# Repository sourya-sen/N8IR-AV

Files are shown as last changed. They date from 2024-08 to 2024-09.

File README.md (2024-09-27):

The N8IR is a standalone experimental audiovisual synthesizer and phrase generator. Designed with a simple set of interconnected audio and visual controls and a modular patchbay, the N8IR creates tightly synced audiovisual patterns, powered by a Teensy microcontroller and CMOS logic chips.

Detailed manual and documentation to follow.

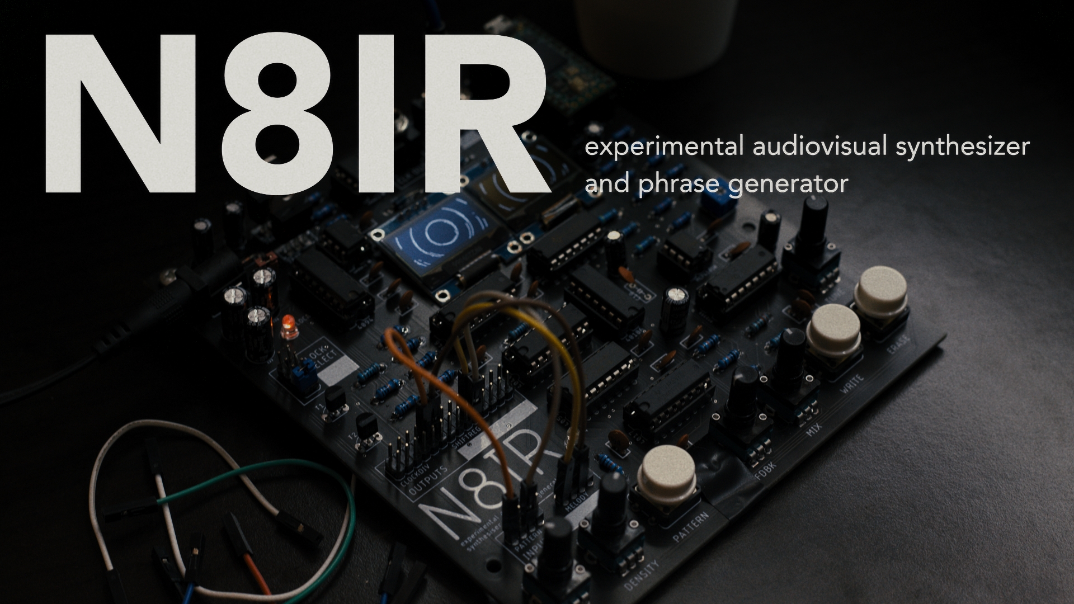
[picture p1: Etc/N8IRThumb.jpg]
N8IR


This project would not be possible without the knowledge shared on the electro-music forums and previous work by Andy Murkin.

More on Lunetta Synthesis: https://hackaday.com/series_of_posts/logic-noise/ <br>
The Melody Generator Circuit on the electro-music forums: https://electro-music.com/forum/topic-42552.html<br>
Andy Murkin’s delay circuit: https://andymurkin.wordpress.com/2018/03/19/piezos-electrets-pt-4-electronics-and-a-very-very-simple-pt2399-echo-delay/<br>

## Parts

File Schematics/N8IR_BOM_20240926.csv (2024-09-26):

Part | Value | Device | Package | Description | CIIVA_IDS | CODE__JEDEC | COMPONENT_LINK_1_DESCRIPTION | COMPONENT_LINK_1_URL | COMPONENT_LINK_3_DESCRIPTION | COMPONENT_LINK_3_URL | DATASHEET | DATASHEET_VERSION | FOOTPRINT_VARIANT_NAME_0 | IMPORTED | IMPORTED_FROM | IMPORT_TS | MF | MPN | PACKAGE | PACKAGE_DESCRIPTION | PACKAGE_VERSION | PIN_0_0_3_INSIDE_EDGE | POPULARITY | PREFIX | PROD_ID | RELEASE_DATE | SF_ID | SF_SKU | SPICEPREFIX | VALUE | VAULT_GUID | VAULT_REVISION
339 | TLC339P | TLC339P | DIL14 | COMPARATOR |  |  |  |  |  |  |  |  |  |  |  |  |  |  |  |  |  |  | 3
4017 | 4017N | 4017N | DIL16 | COUNTER/DIVIDER |  |  |  |  |  |  |  |  |  |  |  |  |  |  |  |  |  |  | 2
4040 | 4040N | 4040N | DIL16 | 12-stage binary/ripple COUNTER |  |  |  |  |  |  |  |  |  |  |  |  |  |  |  |  |  |  | 2
4046 | 4046N | 4046N | DIL16 | Micropower PLL |  |  |  |  |  |  |  |  |  |  |  |  |  |  |  |  |  |  | 1
4051 | 4051N | 4051N | DIL16 | 8-channel ANALOG MULTIPLEXER |  |  |  |  |  |  |  |  |  |  |  |  |  |  |  |  |  |  | 15
4094 | 4094N | 4094N | DIL16 | 8-stage SHIFT/STORE REGISTER, tri-state |  |  |  |  |  |  |  |  |  |  |  |  |  |  |  |  |  |  | 1
7805 | 7805 | 78XXS | 78XXS | VOLTAGE REGULATOR |  |  |  |  |  |  |  |  |  |  |  |  |  |  |  |  |  |  | 18
7809 | 7809 | 78XXS | 78XXS | VOLTAGE REGULATOR |  |  |  |  |  |  |  |  |  |  |  |  |  |  |  |  |  |  | 18
40106 | 40106N | 40106N | DIL14 | Hex SCHMITT TRIGGER |  |  |  |  |  |  |  |  |  |  |  |  |  |  |  |  |  |  | 4
B1 | TEENSYNOSILK | TEENSYNOSILK | TEENSY_NOSILK | Teensy Footprint |  |  |  |  |  |  |  |  |  |  |  |  |  |  |  |  |  |  |  |  |  |  | DEV-12646
C1 | 0.1uF | 0.1UF-KIT-EZ-50V-20% | CAP-PTH-SMALL-KIT | 0.1µF ceramic capacitors |  |  |  |  |  |  |  |  |  |  |  |  |  |  |  |  |  |  |  |  | CAP-08370 |  |  |  |  | 0.1uF
C2 | 0.1uF | 0.1UF-KIT-EZ-50V-20% | CAP-PTH-SMALL-KIT | 0.1µF ceramic capacitors |  |  |  |  |  |  |  |  |  |  |  |  |  |  |  |  |  |  |  |  | CAP-08370 |  |  |  |  | 0.1uF
C3 | 0.1uF | 0.1UF-KIT-EZ-50V-20% | CAP-PTH-SMALL-KIT | 0.1µF ceramic capacitors |  |  |  |  |  |  |  |  |  |  |  |  |  |  |  |  |  |  |  |  | CAP-08370 |  |  |  |  | 0.1uF
C4 | 0.1uF | 0.1UF-KIT-EZ-50V-20% | CAP-PTH-SMALL-KIT | 0.1µF ceramic capacitors |  |  |  |  |  |  |  |  |  |  |  |  |  |  |  |  |  |  |  |  | CAP-08370 |  |  |  |  | 0.1uF
C5 | 0.1uF | 0.1UF-KIT-EZ-50V-20% | CAP-PTH-SMALL-KIT | 0.1µF ceramic capacitors |  |  |  |  |  |  |  |  |  |  |  |  |  |  |  |  |  |  |  |  | CAP-08370 |  |  |  |  | 0.1uF
C6 | 0.1uF | 0.1UF-KIT-EZ-50V-20% | CAP-PTH-SMALL-KIT | 0.1µF ceramic capacitors |  |  |  |  |  |  |  |  |  |  |  |  |  |  |  |  |  |  |  |  | CAP-08370 |  |  |  |  | 0.1uF
C7 | 100uF | 100UF-POLAR-RADIAL-2.5MM-25V-20% | CPOL-RADIAL-2.5MM-6.5MM | 100µF polarized capacitors |  |  |  |  |  |  |  |  |  |  |  |  |  |  |  |  |  |  |  |  | CAP-08439 |  |  |  |  | 100uF
C8 | 0.1uF | 0.1UF-KIT-EZ-50V-20% | CAP-PTH-SMALL-KIT | 0.1µF ceramic capacitors |  |  |  |  |  |  |  |  |  |  |  |  |  |  |  |  |  |  |  |  | CAP-08370 |  |  |  |  | 0.1uF
C9 | 10uF | 10UF-POLAR-RADIAL-2.5MM-25V-20% | CPOL-RADIAL-2.5MM-5MM | 10.0µF polarized capacitors |  |  |  |  |  |  |  |  |  |  |  |  |  |  |  |  |  |  |  |  | CAP-08440 |  |  |  |  | 10uF
C10 | 10uF | 10UF-POLAR-RADIAL-2.5MM-25V-20% | CPOL-RADIAL-2.5MM-5MM | 10.0µF polarized capacitors |  |  |  |  |  |  |  |  |  |  |  |  |  |  |  |  |  |  |  |  | CAP-08440 |  |  |  |  | 10uF
C11 | 0.1uF | 0.1UF-KIT-EZ-50V-20% | CAP-PTH-SMALL-KIT | 0.1µF ceramic capacitors |  |  |  |  |  |  |  |  |  |  |  |  |  |  |  |  |  |  |  |  | CAP-08370 |  |  |  |  | 0.1uF
C12 | 0.1uF | 0.1UF-KIT-EZ-50V-20% | CAP-PTH-SMALL-KIT | 0.1µF ceramic capacitors |  |  |  |  |  |  |  |  |  |  |  |  |  |  |  |  |  |  |  |  | CAP-08370 |  |  |  |  | 0.1uF
C13 | 0.1uF | 0.1UF-KIT-EZ-50V-20% | CAP-PTH-SMALL-KIT | 0.1µF ceramic capacitors |  |  |  |  |  |  |  |  |  |  |  |  |  |  |  |  |  |  |  |  | CAP-08370 |  |  |  |  | 0.1uF
C14 | 10uF | 10UF-POLAR-RADIAL-2.5MM-25V-20% | CPOL-RADIAL-2.5MM-5MM | 10.0µF polarized capacitors |  |  |  |  |  |  |  |  |  |  |  |  |  |  |  |  |  |  |  |  | CAP-08440 |  |  |  |  | 10uF
C15 | 10uF | 10UF-POLAR-RADIAL-2.5MM-25V-20% | CPOL-RADIAL-2.5MM-5MM | 10.0µF polarized capacitors |  |  |  |  |  |  |  |  |  |  |  |  |  |  |  |  |  |  |  |  | CAP-08440 |  |  |  |  | 10uF
C16 | 0.1uF | 0.1UF-KIT-EZ-50V-20% | CAP-PTH-SMALL-KIT | 0.1µF ceramic capacitors |  |  |  |  |  |  |  |  |  |  |  |  |  |  |  |  |  |  |  |  | CAP-08370 |  |  |  |  | 0.1uF
C17 | 0.1uF | 0.1UF-KIT-EZ-50V-20% | CAP-PTH-SMALL-KIT | 0.1µF ceramic capacitors |  |  |  |  |  |  |  |  |  |  |  |  |  |  |  |  |  |  |  |  | CAP-08370 |  |  |  |  | 0.1uF
C18 | 0.1uF | 0.1UF-KIT-EZ-50V-20% | CAP-PTH-SMALL-KIT | 0.1µF ceramic capacitors |  |  |  |  |  |  |  |  |  |  |  |  |  |  |  |  |  |  |  |  | CAP-08370 |  |  |  |  | 0.1uF
C19 | .1uF | C5/3.5 | C5B3.5 | CAPACITOR |  |  |  |  |  |  |  |  |  |  |  |  |  |  |  |  |  |  | 3
C20 | 47uF | 10UF-POLAR-RADIAL-2.5MM-25V-20% | CPOL-RADIAL-2.5MM-5MM | 10.0µF polarized capacitors |  |  |  |  |  |  |  |  |  |  |  |  |  |  |  |  |  |  |  |  | CAP-08440 |  |  |  |  | 10uF
C21 | 0.1uF | 0.1UF-KIT-EZ-50V-20% | CAP-PTH-SMALL-KIT | 0.1µF ceramic capacitors |  |  |  |  |  |  |  |  |  |  |  |  |  |  |  |  |  |  |  |  | CAP-08370 |  |  |  |  | 0.1uF
C22 | 0.1uF | 0.1UF-KIT-EZ-50V-20% | CAP-PTH-SMALL-KIT | 0.1µF ceramic capacitors |  |  |  |  |  |  |  |  |  |  |  |  |  |  |  |  |  |  |  |  | CAP-08370 |  |  |  |  | 0.1uF
C23 | 100uF | 100UF-POLAR-RADIAL-2.5MM-25V-20% | CPOL-RADIAL-2.5MM-6.5MM | 100µF polarized capacitors |  |  |  |  |  |  |  |  |  |  |  |  |  |  |  |  |  |  |  |  | CAP-08439 |  |  |  |  | 100uF
C24 | 0.1uF | 0.1UF-KIT-EZ-50V-20% | CAP-PTH-SMALL-KIT | 0.1µF ceramic capacitors |  |  |  |  |  |  |  |  |  |  |  |  |  |  |  |  |  |  |  |  | CAP-08370 |  |  |  |  | 0.1uF
C25 | 0.1uF | 0.1UF-KIT-EZ-50V-20% | CAP-PTH-SMALL-KIT | 0.1µF ceramic capacitors |  |  |  |  |  |  |  |  |  |  |  |  |  |  |  |  |  |  |  |  | CAP-08370 |  |  |  |  | 0.1uF
C26 | 10uF | 10UF-POLAR-RADIAL-2.5MM-25V-20% | CPOL-RADIAL-2.5MM-5MM | 10.0µF polarized capacitors |  |  |  |  |  |  |  |  |  |  |  |  |  |  |  |  |  |  |  |  | CAP-08440 |  |  |  |  | 10uF
C27 | 100uF | 100UF-POLAR-RADIAL-2.5MM-25V-20% | CPOL-RADIAL-2.5MM-6.5MM | 100µF polarized capacitors |  |  |  |  |  |  |  |  |  |  |  |  |  |  |  |  |  |  |  |  | CAP-08439 |  |  |  |  | 100uF
CLOCK |  | LED3MM | LED_3MM | LED (Generic) |  |  |  |  |  |  |  |  |  |  |  |  |  |  |  |  |  |  |  |  | DIO-08794
CLOCKDIV |  | PINHD-2X6 | 2X06 | PIN HEADER |  |  |  |  |  |  |  |  |  |  |  |  |  |  |  |  |  |  | 8
CLOCKOUT | WQP-PJ301M-12_JACK | WQP-PJ301M-12_JACK | WQP-PJ301M-12_JACK
D1 | BAT42 | BAT42 | DO35-10 | DIODE |  |  |  |  |  |  |  |  |  |  |  |  |  |  |  |  |  |  | 0
D2 | BAT42 | BAT42 | DO35-10 | DIODE |  |  |  |  |  |  |  |  |  |  |  |  |  |  |  |  |  |  | 0
D3 | 1N4148 | SMALL_DIODEDO35-7 | DO35-7 | Small Signal Diode
DENSITY | 100k | 9MM_SNAP-IN_POT_ | 9MM_SNAP-IN_POT | 9mm vertical snap-in pot, Alpha / Panasonic style
ERASE |  | MOMENTARY-SWITCH-SPST-PTH-12MM | TACTILE_SWITCH_PTH_12MM | Momentary Switch (Pushbutton) - SPST |  |  |  |  |  |  |  |  |  |  |  |  |  |  |  |  |  |  |  |  | SWCH-09185 |  |  | COM-09190
FDBK | 100k | 9MM_SNAP-IN_POT_ | 9MM_SNAP-IN_POT | 9mm vertical snap-in pot, Alpha / Panasonic style
FREQ | 100k | 9MM_SNAP-IN_POT_ | 9MM_SNAP-IN_POT | 9mm vertical snap-in pot, Alpha / Panasonic style
J1 |  | POWER_JACKPOWER_JACK_SLOT | POWER_JACK_PTH_SLOT | Power Jack Connector |  |  |  |  |  |  |  |  |  |  |  |  |  |  |  |  |  |  |  |  | CONN-08197
JP4 |  | PINHD-2X4 | 2X04 | PIN HEADER
LM358-1 | LM358 | LM358 | DIP08 | LM358 |  |  |  |  |  |  |  |  |  |  |  |  |  |  |  |  |  |  |  |  | IC-09172 |  |  |  |  | LM358
LM358-2 | LM358 | LM358 | DIP08 | LM358 |  |  |  |  |  |  |  |  |  |  |  |  |  |  |  |  |  |  |  |  | IC-09172 |  |  |  |  | LM358
MCP41050 | MCP41050 | MICROCHIP_MCP41050-I-PMICROCHIP_MCP41050-I-P_0_0 | MICROCHIP_MCP41050-I-P_0 | IN-DPOT-MCP41XXX-8 | 965827 | MS-001 | Manufacturer URL | http://www.microchip.com/ | Package Specification | http://www.microchip.com/stellent/groups/techpub_sg/documents/packagingspec/en012702.pdf | http://ww1.microchip.com/downloads/en/DeviceDoc/11195c.pdf | Jul-2003 | Manufacturer Recommended | yes | vault | 1521866433 | Microchip | MCP41050-I/P | PDIP300-P8 | 8-Lead Plastic Dual In-Line (P) - 300 mil Body [PDIP] | revBB, Aug-2009 | clock |  | U |  | 1331947897 |  |  |  |  | 8499BC26-C1FC-4B90-9420-E4A686EE06B6 | 41824CE8-0B62-48CA-9CA7-4E0BC05643CA
MELODY |  | PINHD-1X4 | 1X04 | PIN HEADER |  |  |  |  |  |  |  |  |  |  |  |  |  |  |  |  |  |  | 91
MIX | 100k | 9MM_SNAP-IN_POT_ | 9MM_SNAP-IN_POT | 9mm vertical snap-in pot, Alpha / Panasonic style
MS4 |  | LED3MM | LED_3MM | LED (Generic) |  |  |  |  |  |  |  |  |  |  |  |  |  |  |  |  |  |  |  |  | DIO-08794
OL96$1 | OLED_0.96_I2C | OLED_0.96_I2C | OLED_0.96_I2C
OL96$2 | OLED_0.96_I2C | OLED_0.96_I2C | OLED_0.96_I2C
OUTPUT | WQP-PJ301M-12_JACK | WQP-PJ301M-12_JACK | WQP-PJ301M-12_JACK
PATTERN |  | PINHD-1X4 | 1X04 | PIN HEADER |  |  |  |  |  |  |  |  |  |  |  |  |  |  |  |  |  |  | 91
PATTERNOFFSET |  | MOMENTARY-SWITCH-SPST-PTH-12MM | TACTILE_SWITCH_PTH_12MM | Momentary Switch (Pushbutton) - SPST |  |  |  |  |  |  |  |  |  |  |  |  |  |  |  |  |  |  |  |  | SWCH-09185 |  |  | COM-09190
PT2399 | PT2399 | PT2399 | DIP-16
R1 | 10k | RESISTOR7MM | 7MM_RESISTOR | Standard resistor, various versions
R2 | 10k | RESISTOR7MM | 7MM_RESISTOR | Standard resistor, various versions
R3 | 10k | RESISTOR7MM | 7MM_RESISTOR | Standard resistor, various versions
R4 | 10k | RESISTOR7MM | 7MM_RESISTOR | Standard resistor, various versions
R5 | 4.7k | RESISTOR7MM | 7MM_RESISTOR | Standard resistor, various versions
R6 | 1k | RESISTOR7MM | 7MM_RESISTOR | Standard resistor, various versions
R7 | 10k | RESISTOR7MM | 7MM_RESISTOR | Standard resistor, various versions
R8 | 10k | RESISTOR7MM | 7MM_RESISTOR | Standard resistor, various versions
R9 | 4.7k | RESISTOR7MM | 7MM_RESISTOR | Standard resistor, various versions
R10 | 4.7k | RESISTOR7MM | 7MM_RESISTOR | Standard resistor, various versions
R11 | 10k | RESISTOR7MM | 7MM_RESISTOR | Standard resistor, various versions
R12 | 4.7k | RESISTOR7MM | 7MM_RESISTOR | Standard resistor, various versions
R13 | 10k | RESISTOR7MM | 7MM_RESISTOR | Standard resistor, various versions
R14 | 4.7k | RESISTOR7MM | 7MM_RESISTOR | Standard resistor, various versions
R15 | 100k | RESISTOR7MM | 7MM_RESISTOR | Standard resistor, various versions
R16 | 100k | RESISTOR7MM | 7MM_RESISTOR | Standard resistor, various versions
R17 | 100k | RESISTOR7MM | 7MM_RESISTOR | Standard resistor, various versions
R18 | 10k | RESISTOR7MM | 7MM_RESISTOR | Standard resistor, various versions
R19 | 100k | RESISTOR7MM | 7MM_RESISTOR | Standard resistor, various versions
R20 | 100k | RESISTOR7MM | 7MM_RESISTOR | Standard resistor, various versions
R21 | 10k | RESISTOR7MM | 7MM_RESISTOR | Standard resistor, various versions
R22 | 1k | RESISTOR7MM | 7MM_RESISTOR | Standard resistor, various versions
R23 | 10k | RESISTOR7MM | 7MM_RESISTOR | Standard resistor, various versions
R24 | 10k | RESISTOR7MM | 7MM_RESISTOR | Standard resistor, various versions
R25 | 10k | RESISTOR7MM | 7MM_RESISTOR | Standard resistor, various versions
R26 | 1k | RESISTOR7MM | 7MM_RESISTOR | Standard resistor, various versions
R27 | 100k | RESISTOR7MM | 7MM_RESISTOR | Standard resistor, various versions
R28 | LDR | R-EU_0204/2V | 0204V | RESISTOR, European symbol |  |  |  |  |  |  |  |  |  |  |  |  |  |  |  |  |  |  | 11 |  |  |  |  |  | R
R29 | 100k | RESISTOR7MM | 7MM_RESISTOR | Standard resistor, various versions
R30 | 2.2k | RESISTOR7MM | 7MM_RESISTOR | Standard resistor, various versions
R31 | 100k | RESISTOR7MM | 7MM_RESISTOR | Standard resistor, various versions
R32 | 10k | RESISTOR7MM | 7MM_RESISTOR | Standard resistor, various versions
R33 | 100k | RESISTOR7MM | 7MM_RESISTOR | Standard resistor, various versions
SHIFTREG |  | PINHD-2X8 | 2X08 | PIN HEADER |  |  |  |  |  |  |  |  |  |  |  |  |  |  |  |  |  |  | 6
SPEED | 100k | 9MM_SNAP-IN_POT_ | 9MM_SNAP-IN_POT | 9mm vertical snap-in pot, Alpha / Panasonic style
T1 |  | 2N4401-NPN-TO92-EBC | TO92-EBC | NPN Transistror |  |  |  |  |  |  |  |  |  |  |  |  |  |  |  |  |  |  | 0
T2 |  | 2N4401-NPN-TO92-EBC | TO92-EBC | NPN Transistror |  |  |  |  |  |  |  |  |  |  |  |  |  |  |  |  |  |  | 0
TNSYPWR |  | PINHD-1X2 | 1X02 | PIN HEADER |  |  |  |  |  |  |  |  |  |  |  |  |  |  |  |  |  |  | 98
VR4 |  | BOURNS_3362P_TRIMMERP | BOURNS_3362P_TRIMMER | 3362 Series
WRITE |  | MOMENTARY-SWITCH-SPST-PTH-12MM | TACTILE_SWITCH_PTH_12MM | Momentary Switch (Pushbutton) - SPST |  |  |  |  |  |  |  |  |  |  |  |  |  |  |  |  |  |  |  |  | SWCH-09185 |  |  | COM-09190

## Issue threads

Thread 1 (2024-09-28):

BOM questions

extremenerble, 2024-09-28:
Hello!

Saw your post on r/synthdiy and am very interested in this project! Two BOM parts questions:

1. What is the value of VR4 trimmer? The BOM I exported from Eagle doesn't have a value
2. Is the C19 capacitor a film type? It's the same value as the passive ceramics but has a different footprint

Thank you for your time and making this available publicly!

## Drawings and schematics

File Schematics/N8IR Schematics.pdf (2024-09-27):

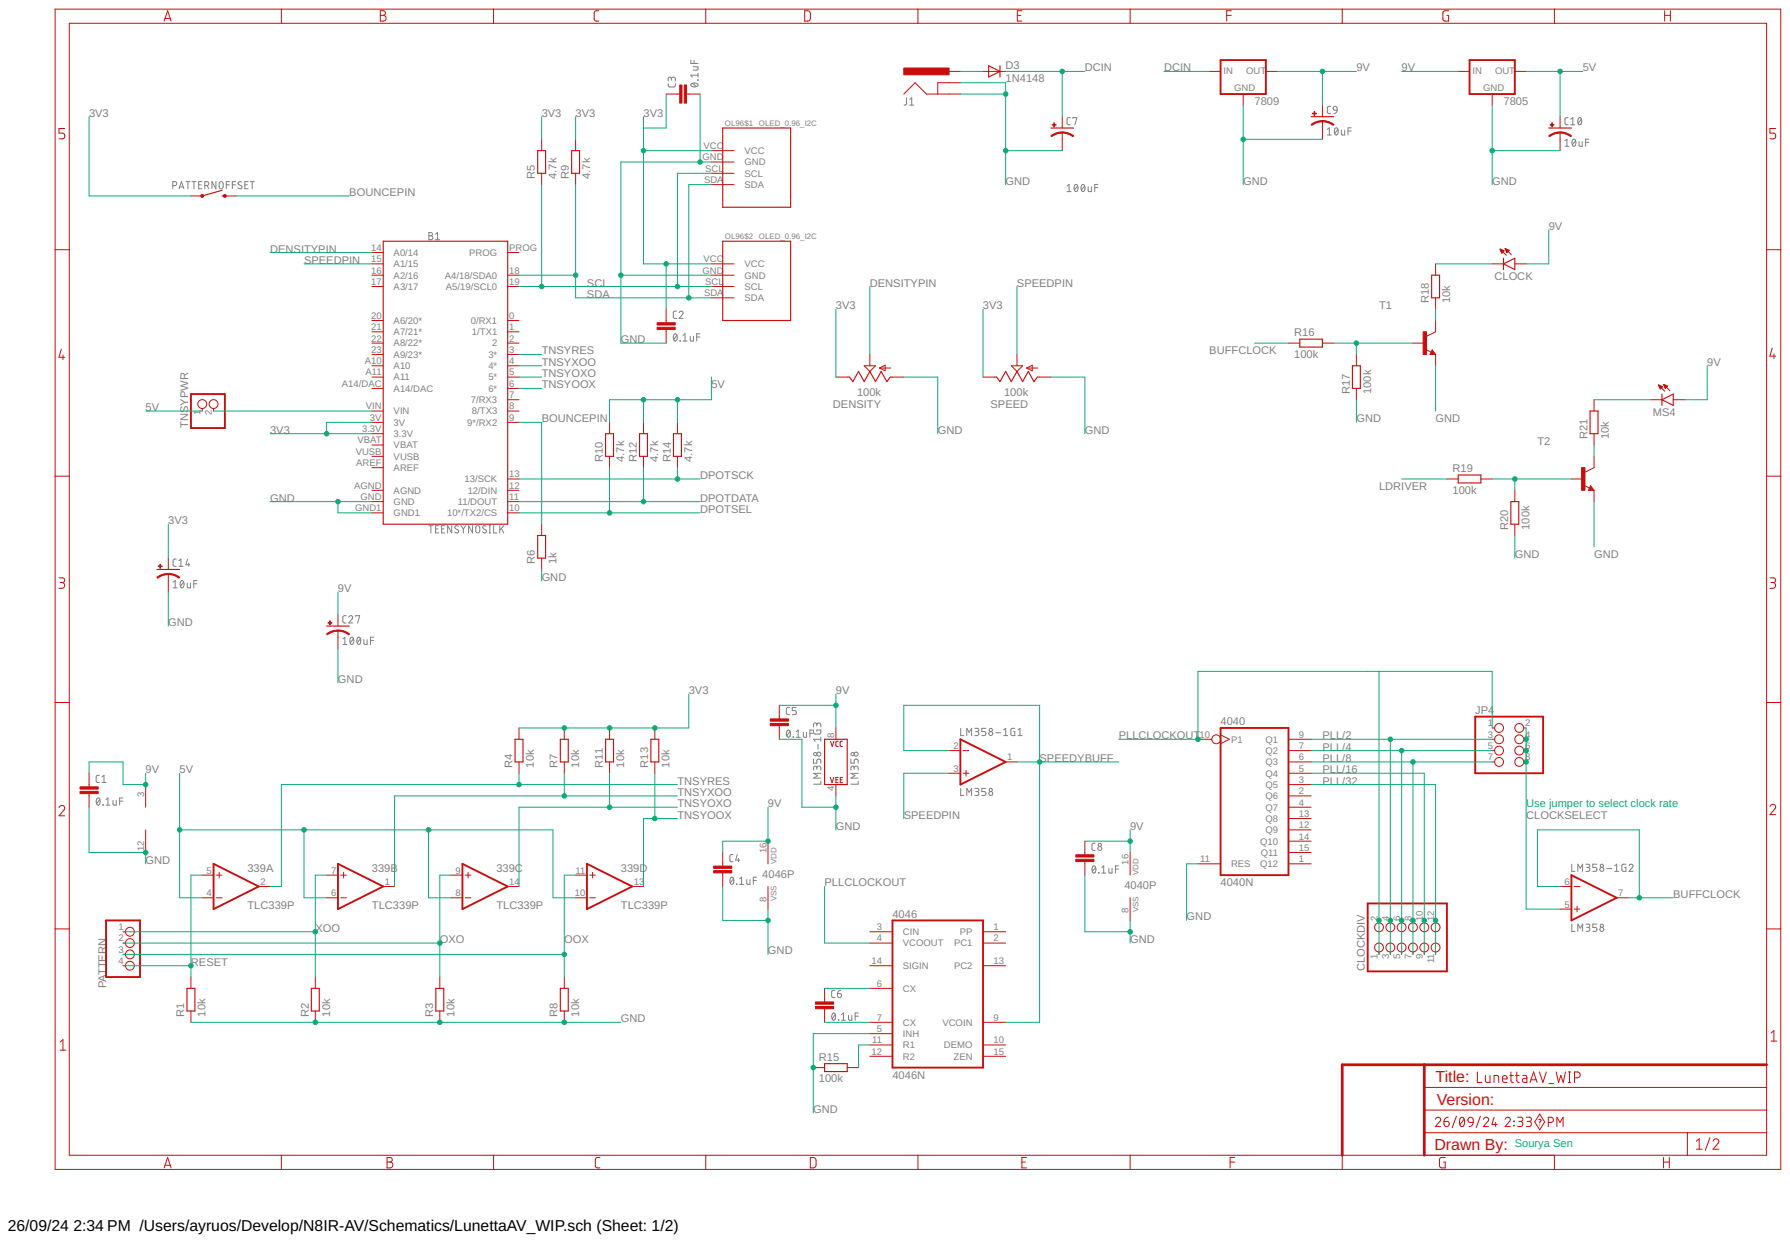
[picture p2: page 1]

5 Q3 PLL/16
4 Q4 PLL/32
3 Q7 2 Q5 13 Q10 12 Q8 14 Q11

Use jumper to select clock rate
CLOCKSELECT

26/09/24 2:34 PM /Users/ayruos/Develop/N8IR-AV/Schematics/LunettaAV_WIP.sch (Sheet: 1/2)

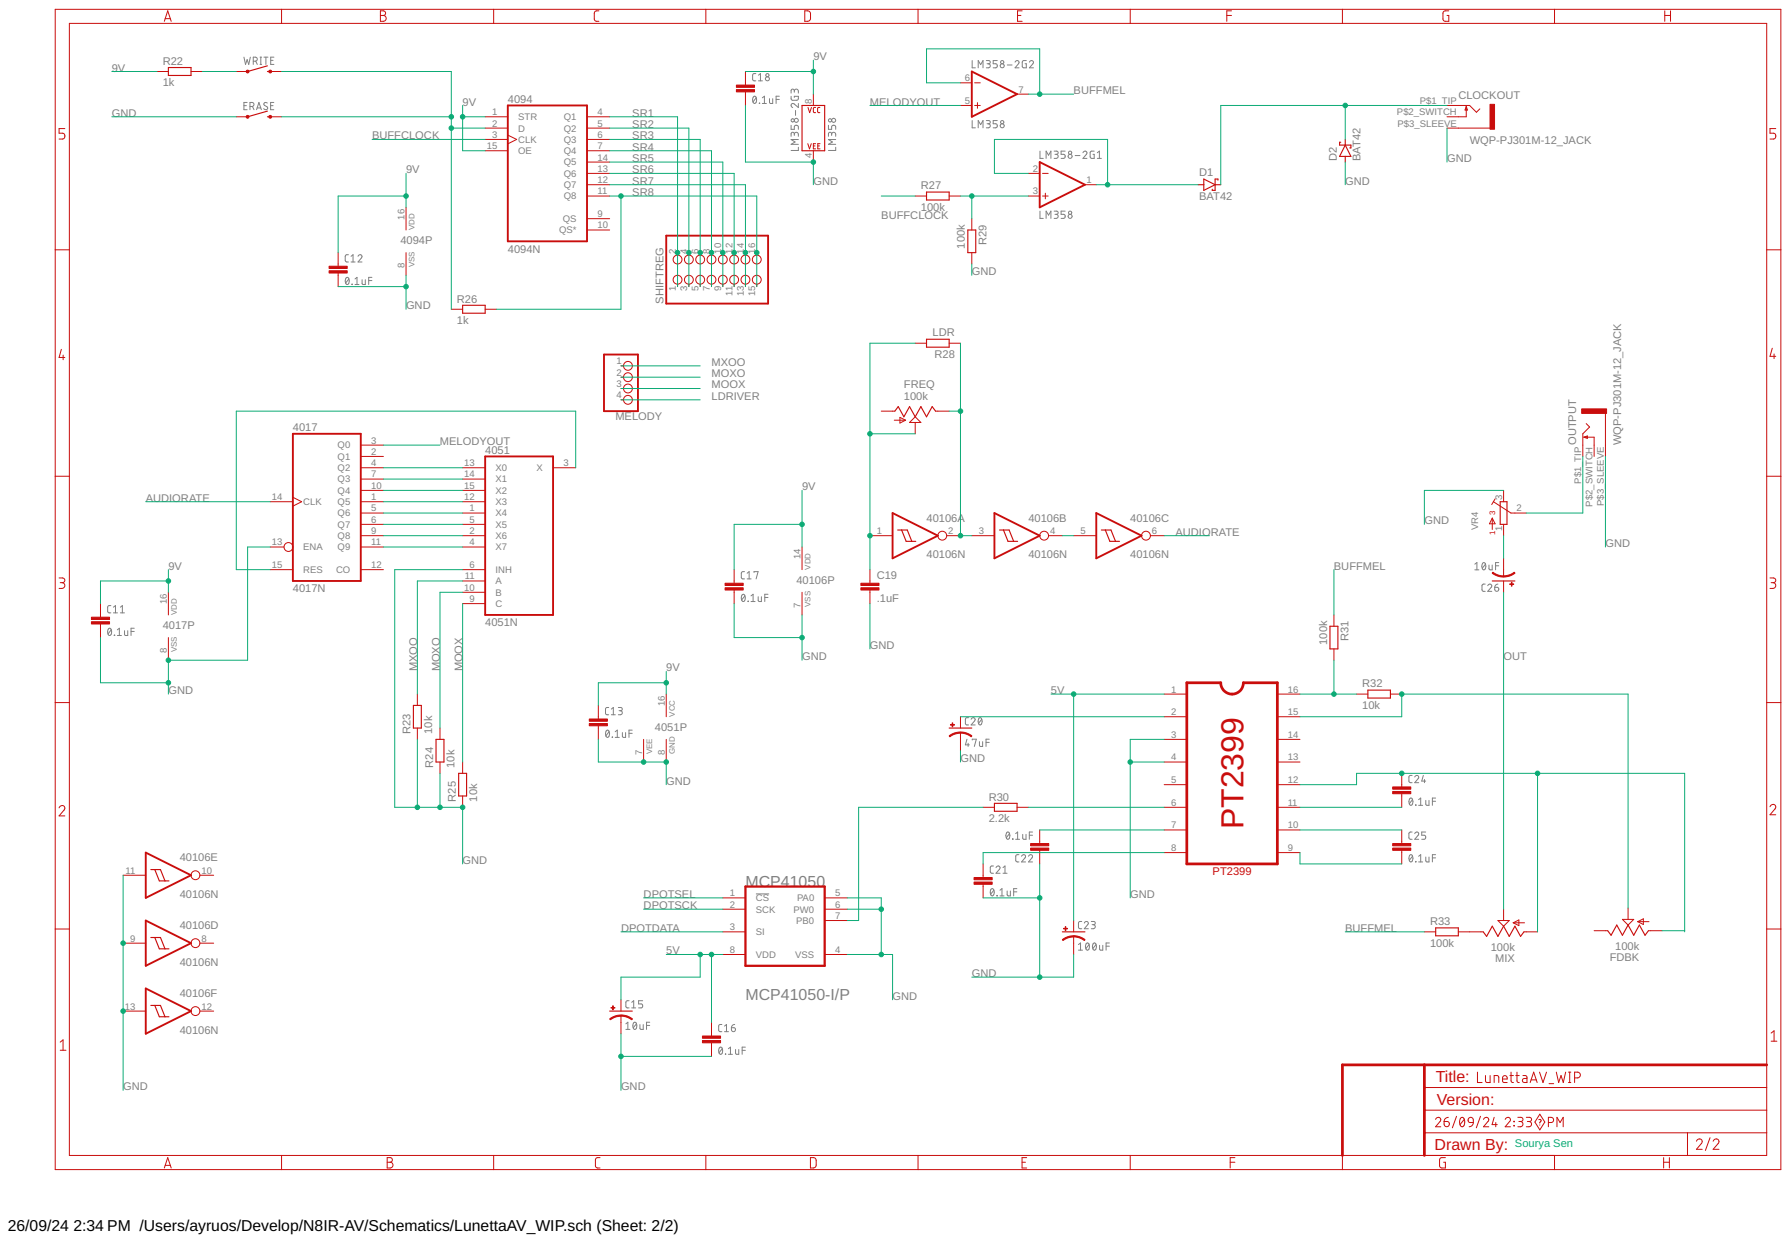
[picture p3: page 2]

6 Q4 SR3
7 QS 13 Q5 SR6 12 Q6

SR4
SR5
SR7

11 Q7 SR8
9 QS* 10 Q8

26/09/24 2:34 PM /Users/ayruos/Develop/N8IR-AV/Schematics/LunettaAV_WIP.sch (Sheet: 2/2)

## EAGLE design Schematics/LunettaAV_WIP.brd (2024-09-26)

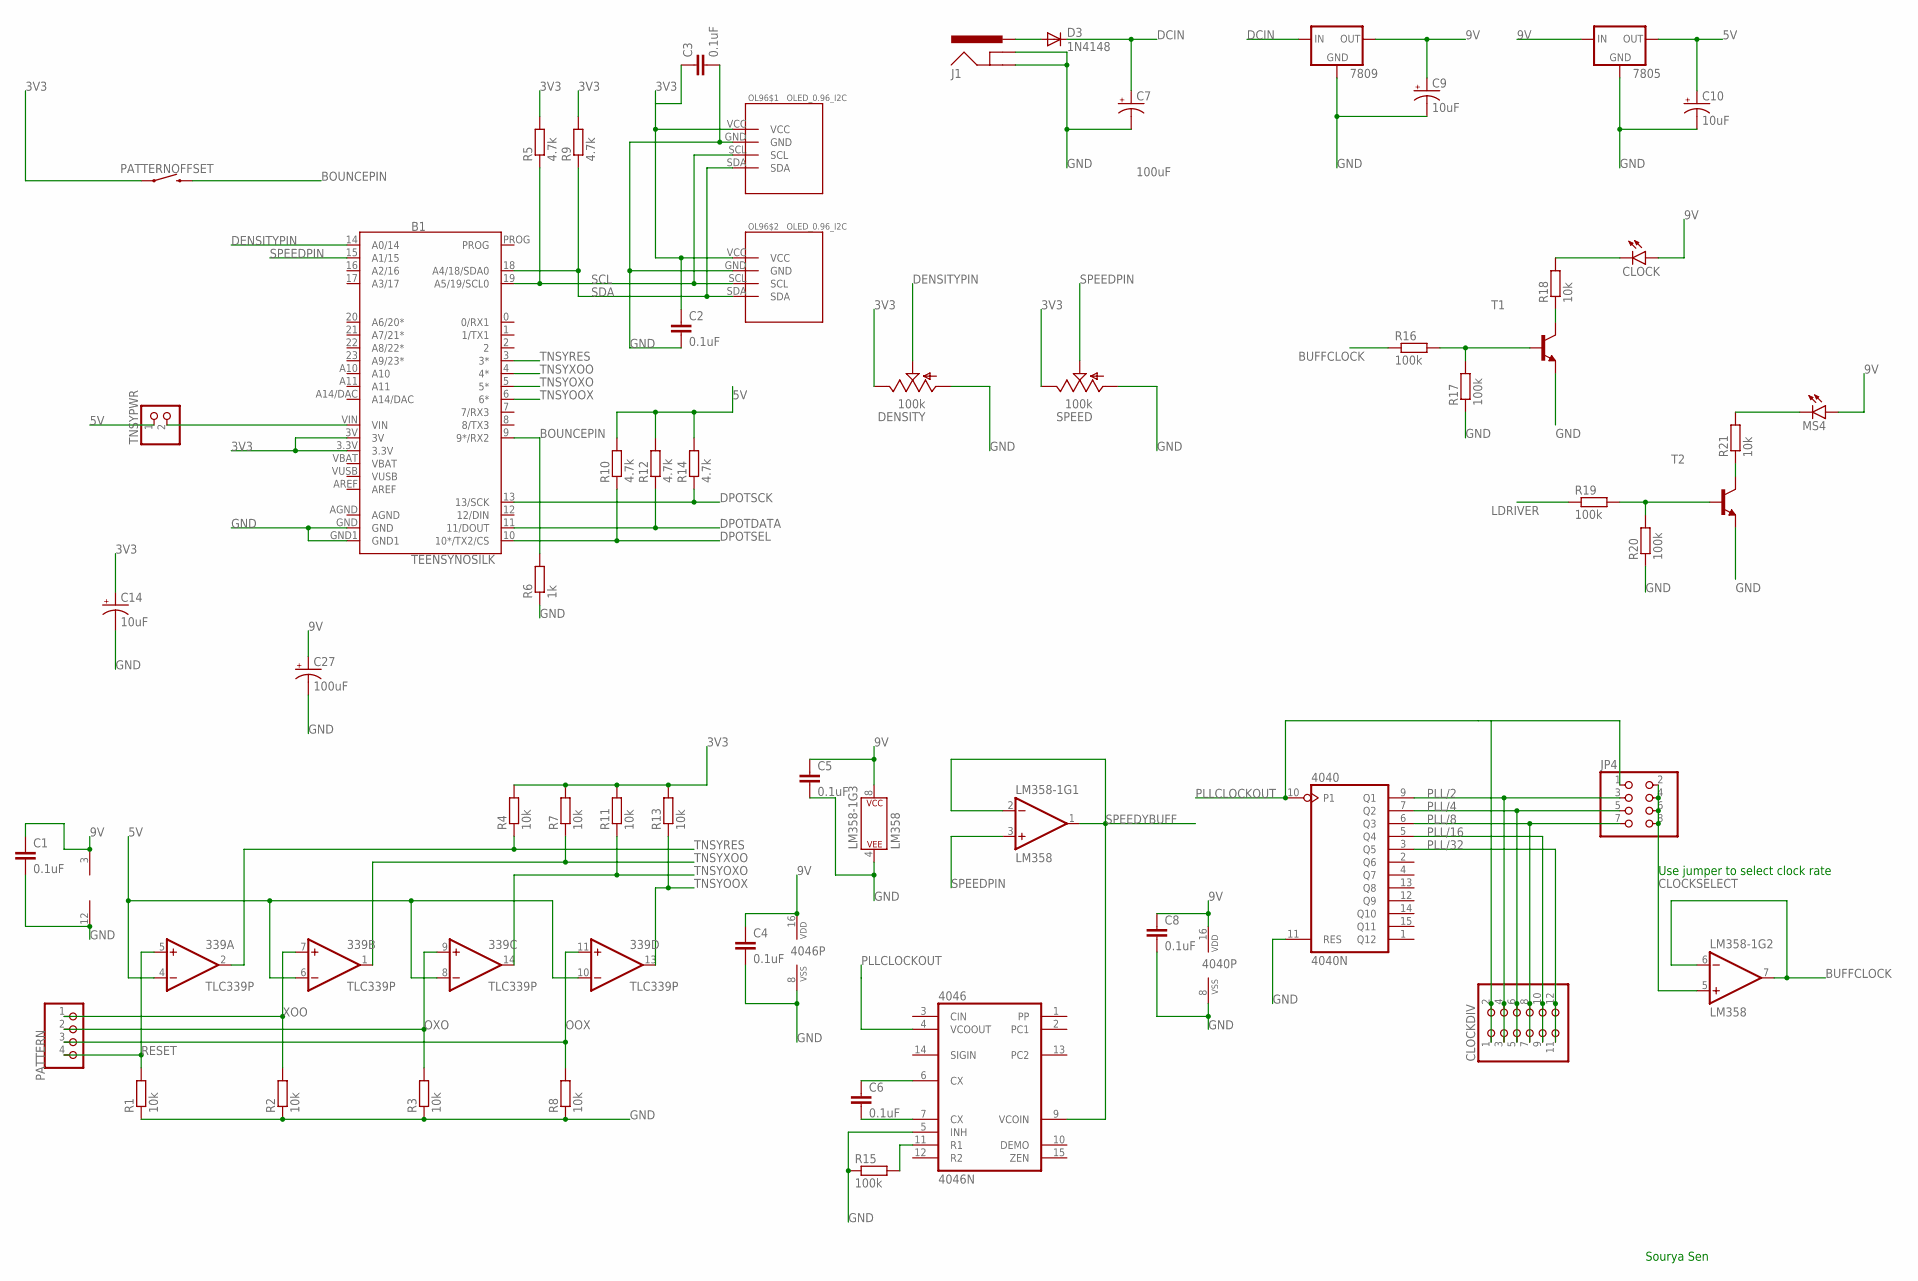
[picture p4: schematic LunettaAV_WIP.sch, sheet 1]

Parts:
339: TLC339P; DIL14
4040: 4040N; DIL16
4046: 4046N; DIL16
7805: 7805; 78XXS
7809: 7809; 78XXS
B1: TEENSYNOSILK; TEENSY_NOSILK
C1, C2, C3, C4, C5, C6, C8: 0.1uF; CAP-PTH-SMALL-KIT
C7, C27: 100uF; CPOL-RADIAL-2.5MM-6.5MM
C9, C10, C14: 10uF; CPOL-RADIAL-2.5MM-5MM
CLOCK: LED3MM; LED_3MM
CLOCKDIV: PINHD-2X6; 2X06
D3: 1N4148; DO35-7
DENSITY: 100k; 9MM_SNAP-IN_POT
J1: POWER_JACKPOWER_JACK_SLOT; POWER_JACK_PTH_SLOT
JP4: PINHD-2X4; 2X04
LM358-1: LM358; DIP08
MS4: LED3MM; LED_3MM
OL96$1, OL96$2: OLED_0.96_I2C
PATTERN: PINHD-1X4; 1X04
PATTERNOFFSET: MOMENTARY-SWITCH-SPST-PTH-12MM; TACTILE_SWITCH_PTH_12MM
R1, R2, R3, R4, R7, R8, R11, R13, R18, R21: 10k; 7MM_RESISTOR
R5, R9, R10, R12, R14: 4.7k; 7MM_RESISTOR
R6: 1k; 7MM_RESISTOR
R15, R16, R17, R19, R20: 100k; 7MM_RESISTOR
SPEED: 100k; 9MM_SNAP-IN_POT
T1, T2: 2N4401-NPN-TO92-EBC; TO92-EBC
TNSYPWR: PINHD-1X2; 1X02

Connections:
3V3: B1.3.3V, B1.3V, C2.1, C3.1, C14.1 (+), DENSITY.3 (E), OL96$1.VCC, OL96$2.VCC, PATTERNOFFSET.1, R4.2, R5.2, R7.2, R9.2, R11.2, R13.2, SPEED.3 (E)
5V: 339.4 (-IN), 339.6 (-IN), 339.8 (-IN), 339.10 (-IN), 7805.OUT, C10.1 (+), R10.2, R12.2, R14.2, TNSYPWR.1; also elsewhere on the board
9V: 339.3 (V+), 4040.16 (VDD), 4046.16 (VDD), 7805.IN, 7809.OUT, C1.1, C4.1, C5.1, C8.1, C9.1 (+), C27.1 (+), CLOCK.A, LM358-1.8 (P$V+), MS4.A; also elsewhere on the board
AGND: B1.AGND
BOUNCEPIN: B1.9 (9*/RX2), PATTERNOFFSET.3 (2), R6.2
BUFFCLOCK: LM358-1.6 (-IN), LM358-1.7 (OUT), R16.1; also elsewhere on the board
CLOCKSELECT: JP4.2, JP4.4, JP4.6, JP4.8, LM358-1.5 (+IN)
DCIN: 7809.IN, C7.1 (+), D3.C
DENSITYPIN: B1.14 (A0/14), DENSITY.2 (S)
DPOTDATA: B1.11 (11/DOUT), R12.1; also elsewhere on the board
DPOTSCK: B1.13 (13/SCK), R14.1; also elsewhere on the board
DPOTSEL: B1.10 (10*/TX2/CS), R10.1; also elsewhere on the board
GND: 339.12 (V-), 4040.8 (VSS), 4040.11 (RES), 4046.5 (INH), 4046.8 (VSS), 7805.GND, 7809.GND, B1.GND, B1.GND1, C1.2, C2.2, C3.2, C4.2, C5.2, C7.2 (-), C8.2, C9.2 (-), C10.2 (-), C14.2 (-), C27.2 (-), DENSITY.1 (A), J1.GND, J1.GNDBREAK, LM358-1.4 (P$V-), OL96$1.GND, OL96$2.GND, R1.1, R2.1, R3.1, R6.1, R8.1, R15.1, R17.1, R20.1, SPEED.1 (A), T1.E, T2.E; also elsewhere on the board
LDRIVER: R19.1; also elsewhere on the board
unnamed: B1.VIN, TNSYPWR.2
unnamed: 4046.7 (CX), C6.2
unnamed: 4046.6 (CX), C6.1
unnamed: 4046.11 (R1), R15.2
unnamed: R16.2, R17.2, T1.B
unnamed: R18.1, T1.C
unnamed: CLOCK.K (C), R18.2
unnamed: R19.2, R20.2, T2.B
unnamed: R21.1, T2.C
unnamed: MS4.K (C), R21.2
unnamed: D3.A, J1.PWR
OOX: 339.11 (+IN), PATTERN.3, R8.2
OXO: 339.9 (+IN), PATTERN.2, R3.2
PLL/2: 4040.9 (Q1), CLOCKDIV.3, CLOCKDIV.4, JP4.3
PLL/4: 4040.7 (Q2), CLOCKDIV.5, CLOCKDIV.6, JP4.5
PLL/8: 4040.6 (Q3), CLOCKDIV.7, CLOCKDIV.8, JP4.7
PLL/16: 4040.5 (Q4), CLOCKDIV.9, CLOCKDIV.10
PLL/32: 4040.3 (Q5), CLOCKDIV.11, CLOCKDIV.12
PLLCLOCKOUT: 4040.10 (P1), 4046.4 (VCOOUT), CLOCKDIV.1, CLOCKDIV.2, JP4.1
RESET: 339.5 (+IN), PATTERN.4, R1.2
SCL: B1.19 (A5/19/SCL0), OL96$1.SCL, OL96$2.SCL, R5.1
SDA: B1.18 (A4/18/SDA0), OL96$1.SDA, OL96$2.SDA, R9.1
SPEEDPIN: B1.15 (A1/15), LM358-1.3 (+IN), SPEED.2 (S)
SPEEDYBUFF: 4046.9 (VCOIN), LM358-1.1 (OUT), LM358-1.2 (-IN)
TNSYOOX: 339.13 (OUT), B1.6 (6*), R13.1
TNSYOXO: 339.14 (OUT), B1.5 (5*), R11.1
TNSYRES: 339.2 (OUT), B1.3 (3*), R4.1
TNSYXOO: 339.1 (OUT), B1.4 (4*), R7.1
VBAT: B1.VBAT
VUSB: B1.VUSB
XOO: 339.7 (+IN), PATTERN.1, R2.2

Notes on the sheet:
Use jumper to select clock rate
Sourya Sen

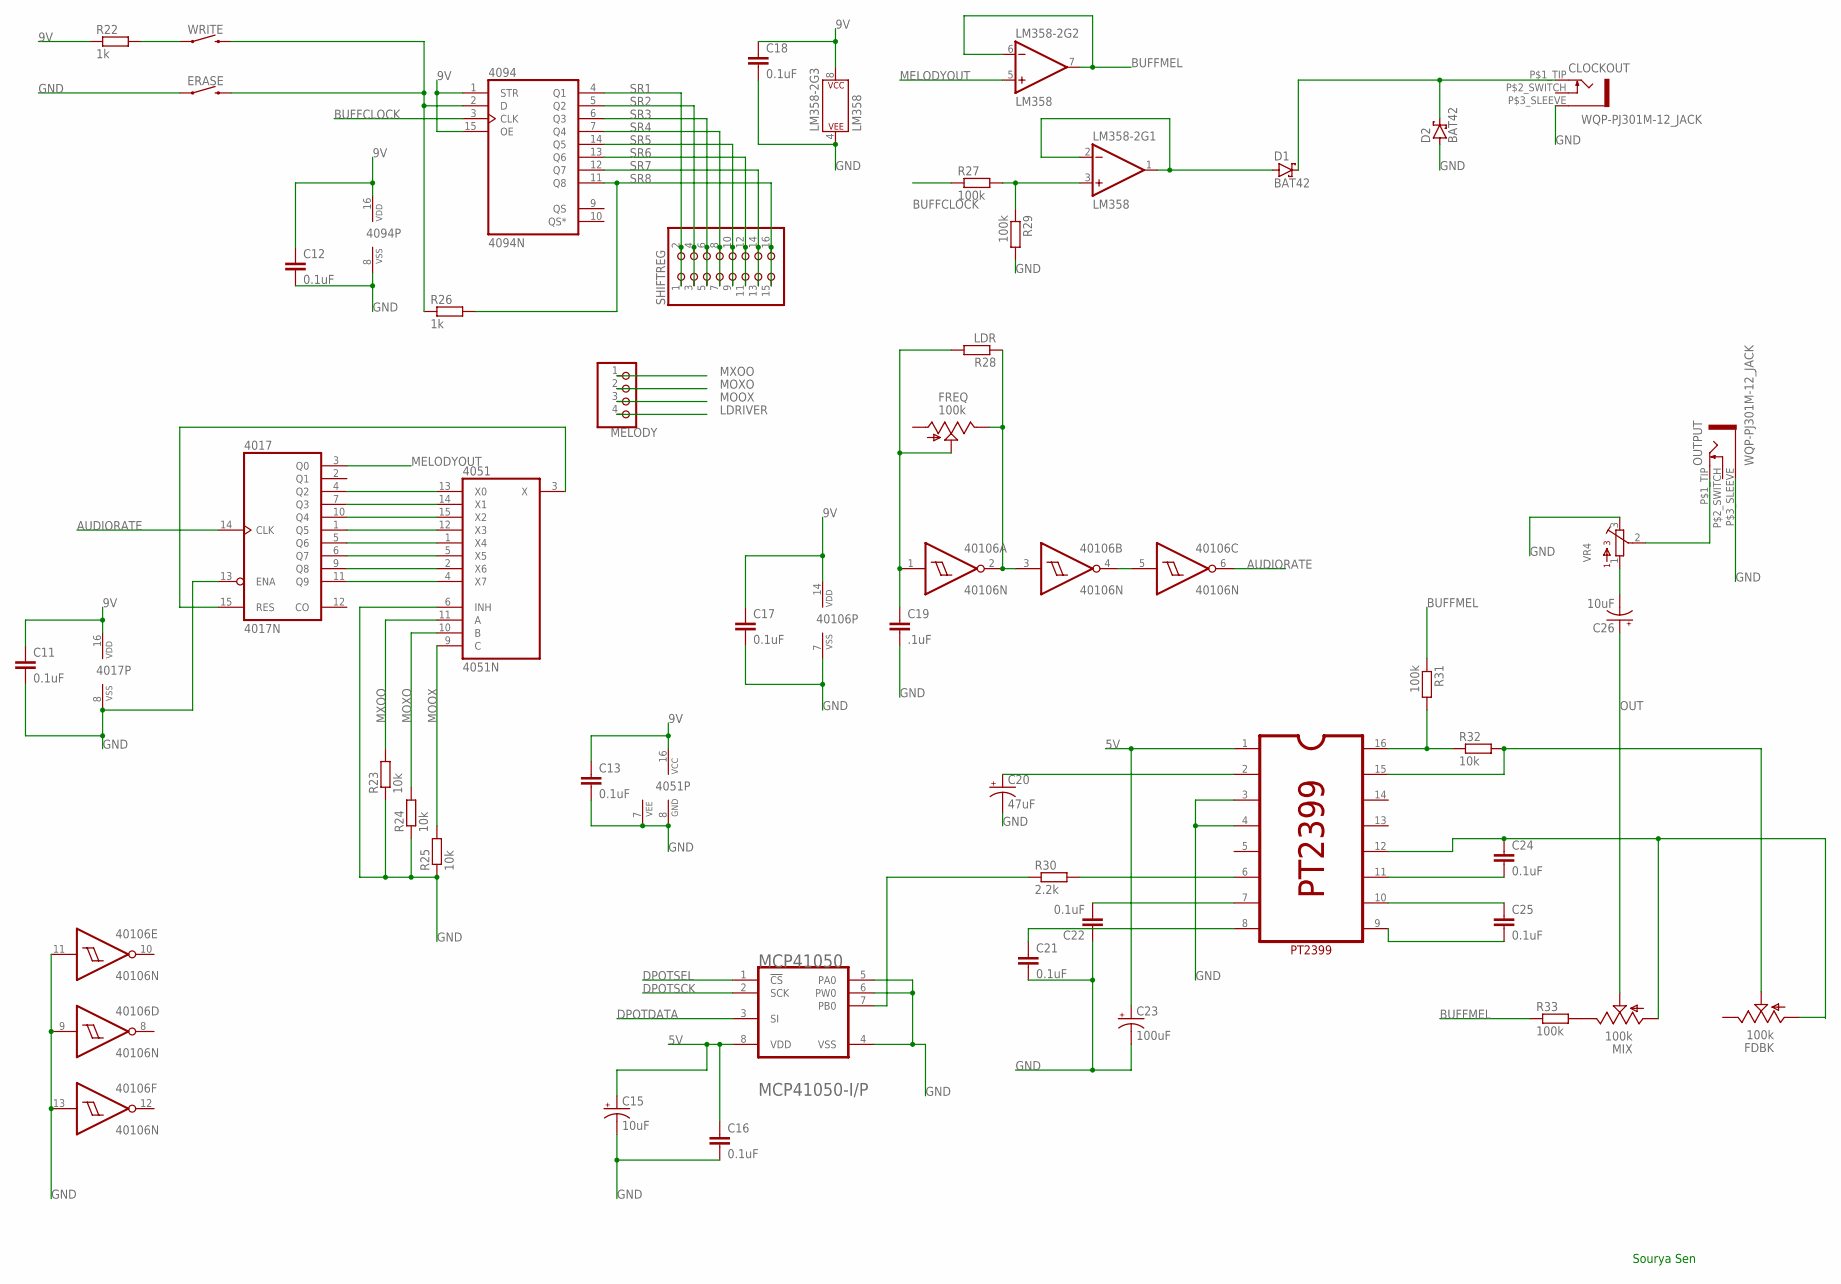
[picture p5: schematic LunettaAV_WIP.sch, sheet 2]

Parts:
4017: 4017N; DIL16
4051: 4051N; DIL16
4094: 4094N; DIL16
40106: 40106N; DIL14
C11, C12, C13, C16, C17, C18, C21, C22, C24, C25: 0.1uF; CAP-PTH-SMALL-KIT
C15, C26: 10uF; CPOL-RADIAL-2.5MM-5MM
C19: .1uF; C5B3.5
C20: 47uF; CPOL-RADIAL-2.5MM-5MM
C23: 100uF; CPOL-RADIAL-2.5MM-6.5MM
CLOCKOUT: WQP-PJ301M-12_JACK
D1, D2: BAT42; DO35-10
ERASE: MOMENTARY-SWITCH-SPST-PTH-12MM; TACTILE_SWITCH_PTH_12MM
FDBK: 100k; 9MM_SNAP-IN_POT
FREQ: 100k; 9MM_SNAP-IN_POT
LM358-2: LM358; DIP08
MCP41050: MCP41050; MICROCHIP_MCP41050-I-P_0
MELODY: PINHD-1X4; 1X04
MIX: 100k; 9MM_SNAP-IN_POT
OUTPUT: WQP-PJ301M-12_JACK
PT2399: PT2399; DIP-16
R22, R26: 1k; 7MM_RESISTOR
R23, R24, R25, R32: 10k; 7MM_RESISTOR
R27, R29, R31, R33: 100k; 7MM_RESISTOR
R28: LDR; 0204V
R30: 2.2k; 7MM_RESISTOR
SHIFTREG: PINHD-2X8; 2X08
VR4: BOURNS_3362P_TRIMMERP; BOURNS_3362P_TRIMMER
WRITE: MOMENTARY-SWITCH-SPST-PTH-12MM; TACTILE_SWITCH_PTH_12MM

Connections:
5V: C15.1 (+), C16.1, C23.1 (+), MCP41050.8 (VDD), PT2399.1; also elsewhere on the board
9V: 4017.16 (VDD), 4051.16 (VCC), 4094.1 (STR), 4094.15 (OE), 4094.16 (VDD), 40106.14 (VDD), C11.1, C12.1, C13.1, C17.1, C18.1, LM358-2.8 (P$V+), R22.1; also elsewhere on the board
AUDIORATE: 4017.14 (CLK), 40106.6 (O)
BUFFCLOCK: 4094.3 (CLK), R27.1; also elsewhere on the board
BUFFMEL: LM358-2.6 (-IN), LM358-2.7 (OUT), R31.1, R33.1
DPOTDATA: MCP41050.3 (SI); also elsewhere on the board
DPOTSCK: MCP41050.2 (SCK); also elsewhere on the board
DPOTSEL: MCP41050.1 (!CS!); also elsewhere on the board
GND: 4017.8 (VSS), 4017.13 (ENA), 4051.6 (INH), 4051.7 (VEE), 4051.8 (GND), 4094.8 (VSS), 40106.7 (VSS), 40106.9 (I), 40106.11 (I), 40106.13 (I), C11.2, C12.2, C13.2, C15.2 (-), C16.2, C17.2, C18.2, C19.2, C20.2 (-), C21.2, C22.1, C23.2 (-), CLOCKOUT.P$3_SLEEVE (1), D2.A, ERASE.1, LM358-2.4 (P$V-), MCP41050.4 (VSS), MCP41050.5 (PA0), MCP41050.6 (PW0), OUTPUT.P$3_SLEEVE (1), PT2399.3, PT2399.4, R23.1, R24.1, R25.1, R29.2, VR4.3; also elsewhere on the board
LDRIVER: MELODY.4; also elsewhere on the board
MELODYOUT: 4017.3 (Q0), LM358-2.5 (+IN)
MOOX: 4051.9 (C), MELODY.3, R25.2
MOXO: 4051.10 (B), MELODY.2, R24.2
MXOO: 4051.11 (A), MELODY.1, R23.2
unnamed: C24.1, FDBK.1 (A), MIX.1 (A), PT2399.12
unnamed: MIX.3 (E), R33.2
unnamed: C25.2, PT2399.9
unnamed: R22.2, WRITE.1
unnamed: 40106.2 (O), 40106.3 (I), FREQ.3 (E), R28.1
unnamed: 40106.4 (O), 40106.5 (I)
unnamed: 40106.1 (I), C19.1, FREQ.2 (S), R28.2
unnamed: C25.1, PT2399.10
unnamed: LM358-2.3 (+IN), R27.2, R29.1
unnamed: D1.A, LM358-2.1 (OUT), LM358-2.2 (-IN)
unnamed: PT2399.6, R30.2
unnamed: C20.1 (+), PT2399.2
unnamed: C22.2, PT2399.7
unnamed: C21.1, PT2399.8
unnamed: 4017.15 (RES), 4051.3 (X)
unnamed: 4017.4 (Q2), 4051.13 (X0)
unnamed: 4017.7 (Q3), 4051.14 (X1)
unnamed: 4017.10 (Q4), 4051.15 (X2)
unnamed: 4017.1 (Q5), 4051.12 (X3)
unnamed: 4017.5 (Q6), 4051.1 (X4)
unnamed: 4017.6 (Q7), 4051.5 (X5)
unnamed: 4017.9 (Q8), 4051.2 (X6)
unnamed: 4017.11 (Q9), 4051.4 (X7)
unnamed: 4094.2 (D), ERASE.3 (2), R26.1, WRITE.3 (2)
unnamed: PT2399.16, R31.2, R32.1
unnamed: FDBK.2 (S), PT2399.15, R32.2
unnamed: C24.2, PT2399.11
unnamed: CLOCKOUT.P$1_TIP (2), D1.C, D2.C
unnamed: MCP41050.7 (PB0), R30.1
unnamed: OUTPUT.P$1_TIP (2), VR4.2
unnamed: C26.2 (-), VR4.1
OUT: C26.1 (+), MIX.2 (S)
SR1: 4094.4 (Q1), SHIFTREG.1, SHIFTREG.2
SR2: 4094.5 (Q2), SHIFTREG.3, SHIFTREG.4
SR3: 4094.6 (Q3), SHIFTREG.5, SHIFTREG.6
SR4: 4094.7 (Q4), SHIFTREG.7, SHIFTREG.8
SR5: 4094.14 (Q5), SHIFTREG.9, SHIFTREG.10
SR6: 4094.13 (Q6), SHIFTREG.11, SHIFTREG.12
SR7: 4094.12 (Q7), SHIFTREG.13, SHIFTREG.14
SR8: 4094.11 (Q8), R26.2, SHIFTREG.15, SHIFTREG.16

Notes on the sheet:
Sourya Sen

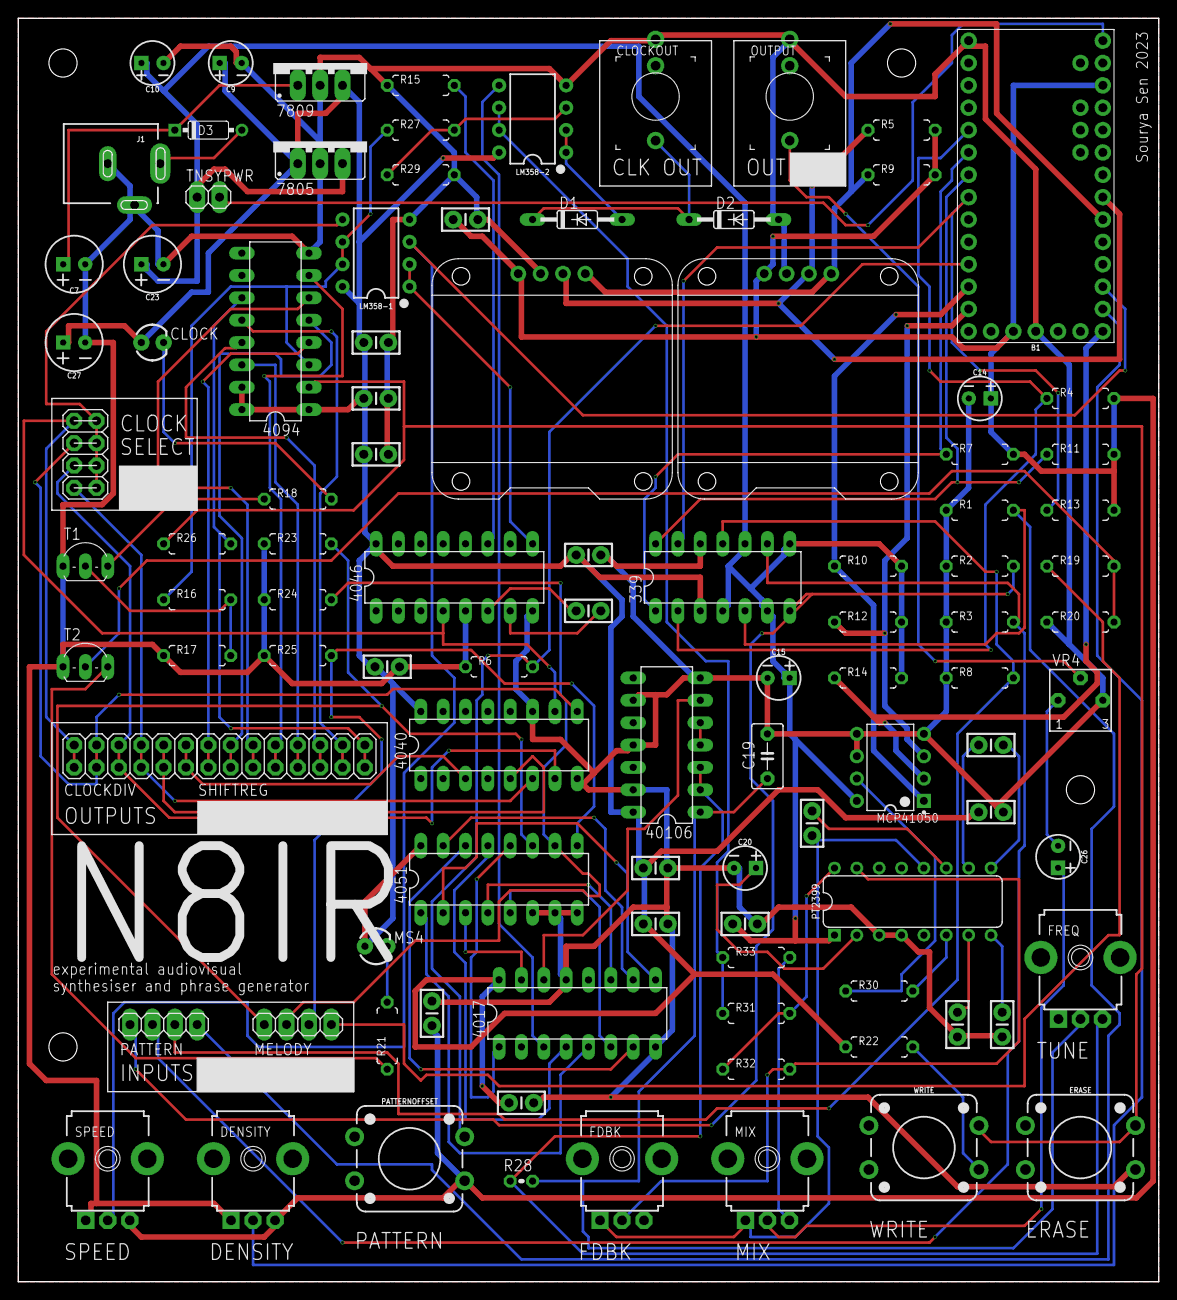
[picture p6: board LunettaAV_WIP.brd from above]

Board: 2 copper layers, 129.5 x 143.5 mm, 105 parts (0 on the bottom side), 88 nets.

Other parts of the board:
U$1, U$2, U$3, U$4: MOUNTING_HOLE

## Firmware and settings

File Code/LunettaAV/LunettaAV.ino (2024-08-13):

#include <SPI.h>
#include <Wire.h>
#include <Adafruit_GFX.h>
#include <Adafruit_SSD1306.h>
#include <FastLED.h>
#include <Bounce.h>

#define SCREEN_WIDTH 128 // OLED display width, in pixels
#define SCREEN_HEIGHT 64 // OLED display height, in pixels

// Declaration for an SSD1306 display connected to I2C (SDA, SCL pins)
// The pins for I2C are defined by the Wire-library.
// On an arduino UNO:       A4(SDA), A5(SCL)
// On an arduino MEGA 2560: 20(SDA), 21(SCL)
// On an arduino LEONARDO:   2(SDA),  3(SCL), ...
#define OLED_RESET     -1 // Reset pin # (or -1 if sharing Arduino reset pin)
#define SCREEN_ADDRESS 0x3C ///< See datasheet for Address; 0x3D for 128x64, 0x3C for 128x32
Adafruit_SSD1306 display(SCREEN_WIDTH, SCREEN_HEIGHT, &Wire, OLED_RESET);

unsigned long lastTime;
unsigned long currentTime;
unsigned long timeInterval = 1000;

int selectedPattern = 3;
int lastPattern = 0;
int _speed, _density = 0;

//Global Variables
float gl_size = 2.;
long double gl_time;
bool gl_refresh = true;
long double gl_lastRefresh = 0;

//Time calculation thing so that it can be reset
long double lastMillis = 0;

#define PI 3.14
#define DENSEMAX 10
#define SPEEDMAX 1000

struct Vec2f {
  float x;
  float y;
};

//Pattern offset
int bouncePin = 9;
Bounce patternButton = Bounce(bouncePin, 5);
int patternOffset = 0;

//Pattern select input
int pinXOOO = 3;
int pinOXOO = 4;
int pinOOXO = 5;
int pinOOOX = 6;

//Analog inputs
int densityPin = 14;
int speedPin = 15;

//Digipot
int slaveSelectPin = 10;

int XOOO, OXOO, OOXO, OOOX = 0;
int inputPattern = 0;
int lastReset = 0;

int lastDigipotValue = 0;

void setup() {
  Serial.begin(9600);

  //OLED SCREEN (I2C) SETUP
  Wire.setSCL(19);
  Wire.setSDA(18);

  // SSD1306_SWITCHCAPVCC = generate display voltage from 3.3V internally
  if (!display.begin(SSD1306_SWITCHCAPVCC, SCREEN_ADDRESS)) {
    Serial.println(F("SSD1306 allocation failed"));
    for (;;); // Don't proceed, loop forever
  }

  // Show initial display buffer contents on the screen --
  // the library initializes this with an Adafruit splash screen.
  // display.display();

  display.clearDisplay();
  display.setTextSize(1);
  display.setTextColor(SSD1306_WHITE);
  display.setCursor(0, 20);
  display.println(F("N8IRAV"));
  display.println(F("v0.0.3"));
  display.println(F("Sourya Sen 2024"));
  display.display();

  delay(1000); // Pause for a second

  // Clear the buffer
  display.clearDisplay();

  //---

  lastTime = millis();

  //Setup the I/O pins
  pinMode(13, OUTPUT); //SCK For Digipot.

  pinMode(bouncePin, INPUT); //this is for the button

  pinMode(densityPin, INPUT); //ANALOGINPUTS
  pinMode(speedPin, INPUT);

  pinMode(pinXOOO, INPUT);
  pinMode(pinOXOO, INPUT);
  pinMode(pinOOXO, INPUT);
  pinMode(pinOOOX, INPUT);

  //Setup Digipot pins
  pinMode(slaveSelectPin, OUTPUT);
  SPI.begin();

  selectedPattern = random(0, 8);
}

void loop() {

  patternButton.update();

  if (patternButton.risingEdge()) {
    patternOffset++;
  }

  XOOO = digitalRead(pinXOOO);
  OXOO = digitalRead(pinOXOO);
  OOXO = digitalRead(pinOOXO);
  OOOX = digitalRead(pinOOOX);

  //  XOOO = 1;
  //  OXOO = 1;
  //  OOXO = 0;
  //  OOOX = 1;

  //  int debugOut = 10000 + 1000 * XOOO + 100 * OXOO + 10 * OOXO + OOOX;
  //  Serial.println(debugOut);

  inputPattern = bToD(100 * OXOO + 10 * OOXO + OOOX);
  selectedPattern = (inputPattern + patternOffset) % 8;

  Serial.print("Selected Pattern: ");
  Serial.println(selectedPattern);


  //Note 29.03.23 ---- > Retest this with this on, currently the reset function is not being used AT ALL
  if (lastReset != XOOO) {
    //RisingEdge
    if (XOOO == 1) {
      //doGlobalReset();
    }
    //Falling Edge
    else {
      //
    }
    lastReset = XOOO;
  }

  int densityValue = analogRead(densityPin);
  _density = map(densityValue, 0, 1023, 1, DENSEMAX);

  int speedValue = analogRead(speedPin);
  _speed = map(speedValue, 0, 1023, 1, SPEEDMAX);

  Serial.print("_speed is: ");
  Serial.println(_speed);
  Serial.print("_density is: ");
  Serial.println(_density);

  int dPotValue = map(densityValue, 0, 1023, 0, 255);

  if (abs(lastDigipotValue - dPotValue) > 10) {
    digitalPotWrite(dPotValue);
    lastDigipotValue = dPotValue;
  }

  if (gl_refresh) display.clearDisplay();
  unsigned long currentTime = millis();

  switch (selectedPattern) {
    case 0:
      drawNoise(_speed, _density);
      break;
    case 1:
      drawGrowingCircles(_speed, _density);
      break;
    case 2:
      drawWrongLine(_speed, _density);
      break;
    case 3:
      drawRotationalSquarePattern(_speed, _density);
      break;
    case 4:
      drawPulsarBalls(_speed, _density);
      break;
    case 5:
      //drawMatrix(_speed, _density);
      drawCircleLines(_speed, _density);
      break;
    case 6:
      drawNoisyCircles(_speed, _density);
      break;
    case 7:
//      drawSimplexNoise();
      drawMovingLines(_speed, _density);
      break;
  }

  if (lastPattern != selectedPattern) {
    display.ssd1306_command(SSD1306_SETSTARTLINE | 0);
    doResetGlobals();
    lastPattern = selectedPattern;
  }

  display.display();

  long double timeDelta = millis() - lastMillis;
  gl_time += timeDelta;

  lastMillis = millis();

}

//-------------------------------------------------------------
//FUNCTIONS FOR MAIN
//-------------------------------------------------------------
int bToD(unsigned num) {
  unsigned res = 0;

  for (int i = 0; num > 0; ++i) {
    if ((num % 10) == 1) res += (1 << i);
    num /= 10;
  }

  return res;
}

//-------------------------------------------------------------
void doResetGlobals() {
  gl_size = 0.;
  gl_time = 0;
  gl_lastRefresh = 0;
}

//-------------------------------------------------------------
int digitalPotWrite(unsigned int value) {
  SPI.beginTransaction(SPISettings(4000000, MSBFIRST, SPI_MODE0));
  //take the SS pin low.
  digitalWrite(slaveSelectPin, LOW);
  //send the write command.
  SPI.transfer(B00010001);
  //send the value
  SPI.transfer(value);
  //take the SS pin high.
  digitalWrite(slaveSelectPin, HIGH);
  SPI.endTransaction();
}

//-------------------------------------------------------------
//-------------------------------------------------------------
//ALL PATTERNS BELOW
//-------------------------------------------------------------
//-------------------------------------------------------------

//-------------------------------------------------------------
//0 -> WHITE NOISE
//-------------------------------------------------------------
void drawNoise(int spd, int dns) {
  gl_refresh = true;
  int randMax = DENSEMAX + 2;
  for (int x = 0; x < display.width(); x++) {
    for (int y = 0; y < display.width(); y++) {
      int r = random(0, (randMax - dns));
      if (r  == 1) {
        display.drawPixel(x, y, SSD1306_WHITE);
      }
    }
  }
}

//-------------------------------------------------------------
//1 - > GROWING CIRCLES
//-------------------------------------------------------------
void drawGrowingCircles(int spd, int dns) {
  gl_refresh = true;
  float increment = float(spd) / float(SPEEDMAX) * 10.;
  increment = constrain(increment, 1., 10.);
  
  for (int i = 1; i <= dns; i += 1) {
    display.drawCircle(display.width() / 2, display.height() / 2, i * gl_size / 2, SSD1306_WHITE);

  }

  display.display();

  int smallestSize = gl_size / 2;

  if (smallestSize > display.width() / 4) gl_size = 0.; //this is slightly random but oh well so is life
  gl_size += increment;
}

//-------------------------------------------------------------
//2 - > ROTATIONAL SQUARES
//-------------------------------------------------------------
void drawRotationalSquarePattern(int spd, int dns) {
  gl_refresh = true;
  for (int i = 0; i < dns + 3; i ++) {
    int mappedSpeed = map(spd, 1, 1000, 10, 1);
    //    Serial.println(mappedSpeed);
    drawRotatedSquare(i * 2, i * 2, gl_time / (10. * mappedSpeed) * i);
  }
}

//CORE FUNCTION
//-------------------------------------------------------------
void drawRotatedSquare(int x, int y, float theta) {
  Vec2f p1, p2, p3, p4;

  p1.x = 2 * -x;
  p1.y = 2 * y;

  p2.x = 2 * x;
  p2.y = 2 * y;

  p3.x = 2 * x;
  p3.y = 2 * -y;

  p4.x = 2 * -x;
  p4.y = 2 * -y;

  rotateVec2f(p1, theta);
  rotateVec2f(p2, theta);
  rotateVec2f(p3, theta);
  rotateVec2f(p4, theta);

  display.drawLine(p1.x, p1.y, p2.x, p2.y, SSD1306_WHITE);

  display.drawLine(p2.x, p2.y, p3.x, p3.y, SSD1306_WHITE);

  display.drawLine(p3.x, p3.y, p4.x, p4.y, SSD1306_WHITE);

  display.drawLine(p4.x, p4.y, p1.x, p1.y, SSD1306_WHITE);

}

//-------------------------------------------------------------
//3 - > SQUIGGLY LINE
//-------------------------------------------------------------
void drawWrongLine(int spd, int dns) {
  gl_refresh = true;
  int step = map(spd, 1, 1000, 64, 1);
  float lastx = -999;
  float lasty = -999;
  float y = display.height() / 2;
  for (int x = 0; x < display.width() + step ; x += step) {
    y = display.height() / 2 + random(-(dns * 2), (dns * 2));
    if (lastx > -999) {
      display.drawLine(x, y, lastx, lasty, SSD1306_WHITE);
    }
    lastx = x;
    lasty = y;
  }
}

//-------------------------------------------------------------
//4 - > PULSAR BALLS
//-------------------------------------------------------------
//This entire function probably can and should be written better
void drawPulsarBalls(int spd, int dns) {
  gl_refresh = true;

  int mappedSpeedForRadius = map(spd, 1, SPEEDMAX, 5, 20);

  float rad = sin(gl_time / 1000. * mappedSpeedForRadius);
  int radiusMax = map(dns, 1, DENSEMAX, 2, 6);
  rad = map(rad, -1, 1, 2, radiusMax);

  float mappedSpeedForTheta = map(spd, 1, SPEEDMAX, 10, 2);
  //  Serial.println(mappedSpeedForTheta);

  drawRotatedCircle(-6, 6, gl_time / mappedSpeedForTheta, rad);
  drawRotatedCircle(6, 6, gl_time / mappedSpeedForTheta, rad);
  drawRotatedCircle(6, -6, gl_time / mappedSpeedForTheta, rad);
  drawRotatedCircle(-6, -6, gl_time / mappedSpeedForTheta, rad);

  float rad2 = map(rad, 1, 5, radiusMax + 1, 1);
  display.fillCircle(display.width() / 2, display.height() / 2, rad2, SSD1306_WHITE);

  drawRotatedCircle(-12, 6, gl_time / mappedSpeedForTheta, rad - 1);
  drawRotatedCircle(12, 6, gl_time / mappedSpeedForTheta, rad - 1);
  drawRotatedCircle(12, -6, gl_time / mappedSpeedForTheta, rad - 1);
  drawRotatedCircle(-12, -6, gl_time / mappedSpeedForTheta, rad - 1);

  drawRotatedCircle(-6, 12, gl_time / mappedSpeedForTheta, rad - 1);
  drawRotatedCircle(6, 12, gl_time / mappedSpeedForTheta, rad - 1);
  drawRotatedCircle(6, -12, gl_time / mappedSpeedForTheta, rad - 1);
  drawRotatedCircle(-6, -12, gl_time / mappedSpeedForTheta, rad - 1);
}

//CORE ROTATIONAL CIRCLE FUNCTION
//-------------------------------------------------------------
void drawRotatedCircle(int x, int y, float theta, int radius) {

  float radtheta = theta * PI / 180.;

  float costheta = cos(radtheta);
  float sintheta = sin(radtheta);

  float xprime = x * costheta  - y * sintheta;
  float yprime = x * sintheta + y * costheta;

  display.fillCircle(display.width() / 2 + 2 * xprime, display.height() / 2 + 2 * yprime, radius, SSD1306_WHITE);
}

//-------------------------------------------------------------
//5 - > MATRIX
//-------------------------------------------------------------
void drawMatrix(int spd, int dns) {

  int refreshTime = map(spd, 1, SPEEDMAX, 800, 100);
  int density = map(dns, 1, DENSEMAX, 1, 16);

  if (gl_time - gl_lastRefresh >= refreshTime) {
    display.clearDisplay();
    gl_refresh = true;
    gl_lastRefresh = gl_time;
    //    Serial.println(int(gl_time));
    //    Serial.println(int(gl_lastRefresh));
  }

  if (gl_refresh) {
    display.setTextSize(1);
    display.cp437(true);
    for (int x = 0; x < display.width(); x += 8) {
      for (int y = 0; y < display.height(); y += 8) {
        int selector = random(0, 8 + y / density);
        int rc = random(256);
        display.setCursor(x, y);
        switch (selector) {
          case 0:
            display.write(' ');
            break;
          case 1:
            display.write(x + gl_time / 100.);
            break;
          case 2:
            display.write(y + gl_time / 100.);
            break;
          case 3:
            display.fillRect(x, y, 4, 4, SSD1306_WHITE);
            break;
          case 4:
            display.fillRect(x, y, 4, 4, SSD1306_WHITE);
            break;
          default:
            display.write(' ');
            break;
        }
      }
    }
    gl_refresh = false;
  }

  if (!gl_refresh) {
    display.ssd1306_command(SSD1306_SETSTARTLINE | (64 - int(gl_time / 100.) % 64));
  }

  for (int x = 0; x < display.width(); x += 8) {
    for (int y = 0; y < display.height(); y += 8) {
      int r = random(0, 512);
      if (r == 1) {
        int t = random(0, 2);
        if (t == 0) {
          display.fillRect(x, y, 4, 4, SSD1306_WHITE);
        } else {
          int c = random(256);
          display.setCursor(x, y);
          display.write(c);
        }
      }
    }
  }
}

//-------------------------------------------------------------
//6 - > NOISY CIRCLES
//-------------------------------------------------------------
void drawNoisyCircles(int spd, int dns) {
  gl_refresh = true;

  float timeFactor = map(spd, 1, SPEEDMAX, 1000., 10.);
  float sizeFactor = map(dns, 1, DENSEMAX, 1, 16);

  for (int num = 0; num < 8; num ++) {
    float lastx = -999;
    float lasty = -999;
    for (int i = 0; i < 361; i += 8) {
      float radtheta = i * PI / 180.;
      float noisy = inoise8(i * gl_time / timeFactor);

      noisy = map(noisy, -70, 70, 0, 16);

      float radius = 4 * sin(i + gl_time / timeFactor) + num * sizeFactor + noisy;

      float x = display.width() / 2 + radius * cos(radtheta);
      float y = display.height() / 2 + radius * sin(radtheta);

      float firstx, firsty;

      if(i==0){
        firstx = x;
        firsty = y;
      }

      if (lastx > -999 && i < 360) {
        display.drawLine(x, y, lastx, lasty, SSD1306_WHITE);
      }

      if(i == 360){
        display.drawLine(lastx, lasty, firstx, firsty, SSD1306_WHITE);
      }

      lastx = x;
      lasty = y;
    }
  }

}

//-------------------------------------------------------------
//-------------------------------------------------------------
//FUNCTIONS FOR GEOMETRY MANIPULATION
//-------------------------------------------------------------
//-------------------------------------------------------------

//ROTATE VEC2F AROUND THETA
//-------------------------------------------------------------
void rotateVec2f(Vec2f &vec, float theta) {
  float radtheta = theta * PI / 180.;

  float costheta = cos(radtheta);
  float sintheta = sin(radtheta);

  float xprime = vec.x * costheta  - vec.y * sintheta;
  float yprime = vec.x * sintheta + vec.y * costheta;

  //  xprime += display.width()/2;
  //  yprime += display.height()/2;

  vec.x = display.width() / 2 + xprime;
  vec.y = display.height() / 2 + yprime;
}

//------------------------------------------------------------
float customNoise(float val){
  float returnValue = pow(sin(val), 3);
  return returnValue;

  //This is from Pearson M. Generative Art
}

//-------------------------------------------------------------
//-------------------------------------------------------------
//-------------------------------------------------------------
//-------------------------------------------------------------


//SKETCHPAD
//------------------------------------------------------------
void drawCircleLines(int spd, int dns){
  gl_refresh = true;

  float inc = map(dns, 1, DENSEMAX, 10, 1);
  float jitterC = map(spd, 1, SPEEDMAX, 1, 12);

  int signx = random(100);
  
  if (signx < 50){
    signx = -1;
  } else {
    signx = 1;
  }

  int signy = random(100);
  
  if (signy < 50){
    signy = -1;
  } else {
    signy = 1;
  }

  for(int angle=0; angle<360; angle+=inc * 6){

    float radtheta = angle * PI / 180.;
    
    float cx = display.width()/2 + random(jitterC) * signx;
    float cy = display.height()/2 + random(jitterC) * signy;

    float speedMultiplier = map(spd, 1, SPEEDMAX, 0.1, 1.0);

    float constantr = map(spd, 1, SPEEDMAX, 8, 32);
    float randomr = 32 - constantr;

    float radius = constantr + random(randomr);

    float angleOffset = gl_time*speedMultiplier;
    
    float px = cx + (radius * cos(radtheta + angleOffset));
    float py = cy + (radius * sin(radtheta + angleOffset));

    display.drawLine(cx, cy, px, py, SSD1306_WHITE);
  }
  
}

//------------------------------------------------------------
void drawMovingLines(int spd, int dns){
  gl_refresh = true;
  
  int maxLines = map(dns, 1, DENSEMAX, 1, 6);

  float speedFactor = map(spd, 1, SPEEDMAX, 0.5, 11.);

  float yOffset = int(gl_time * speedFactor) % int(display.height()/maxLines);

  for(int i = 0; i<maxLines; i++){
    
    float yPos = i * display.height()/maxLines + yOffset;

    float randomOffset = map(spd, 1, SPEEDMAX, 1, display.width()/2);
      
    float xOffset = random(randomOffset);
    
    display.drawLine(xOffset, yPos, display.width() - xOffset, yPos, SSD1306_WHITE);
  }
  
}


//------------------------------------------------------------


void drawStrobes() {
  int strobeInterval = 500;

  unsigned long cTime = millis();
  static unsigned long lastStrobe = 0;
  static bool state = false;

  if (cTime - lastStrobe >= strobeInterval) {
    lastStrobe = cTime;

    if (state) {
      display.fillScreen(WHITE);
    } else {
      display.clearDisplay();
    }
    state = !state;
  }

}

//-------------------------------------------------------------
void drawSimplexNoise() {
  gl_refresh = true;

  for (int x = 0; x < display.width(); x += 2) {
    for (int y = 0; y < display.width(); y += 2) {
      int r = inoise8(x * gl_time / 10., y * gl_time / 100.);
      r = map(r, -70, 70, 0, 255);
      //      Serial.println(r);
      if (r > 300) {
        display.drawPixel(x, y, SSD1306_WHITE);
      } else {
        // DO NOTHING :)
      }
    }
  }
}

//-------------------------------------------------------------
void drawVector() {
  float x = sin(110. * millis() / 1.);
  float y = sin(55. * millis() / 1.);

  float mappedx = map(x, -1., 1., -display.height() / 2, display.height() / 2);
  float mappedy = map(y, -1., 1., -display.height() / 2, display.height() / 2);

  display.drawCircle(mappedx + display.width() / 2, mappedy + display.height() / 2, 1, SSD1306_WHITE);
}

//-------------------------------------------------------------
//void drawTestFlight() {
//  float radius = sin(millis() / 100.0);
//  radius = map(radius, -1, 1, 1, 5);
//
//  drawRotationThing(-6, 6, millis() / 10., radius);
//  drawRotationThing(6, 6, millis() / 10., radius);
//  drawRotationThing(6, -6, millis() / 10., radius);
//  drawRotationThing(-6, -6, millis() / 10., radius);
//
//  float rad2 = map(radius, 1, 5, 10, 1);
//  display.fillCircle(display.width() / 2, display.height() / 2, rad2, SSD1306_WHITE);
//
//  drawRotationThing(-12, 6, millis() / 10., radius);
//  drawRotationThing(12, 6, millis() / 10., radius);
//  drawRotationThing(12, -6, millis() / 10., radius);
//  drawRotationThing(-12, -6, millis() / 10., radius);
//
//  drawRotationThing(-6, 12, millis() / 10., radius);
//  drawRotationThing(6, 12, millis() / 10., radius);
//  drawRotationThing(6, -12, millis() / 10., radius);
//  drawRotationThing(-6, -12, millis() / 10., radius);
//}

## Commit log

2021-06-21 add WIP Teensy code
2021-06-23 Initial commit schm for Teensy
    [LunettaAV_WIP.sch]
2021-06-23 make schematics prettier
    [LunettaAV_WIP.sch]
2021-06-23 fix analog input pins
    [LunettaAV_WIP.sch]
2021-06-23 Add 358 and 4046 sections
    [LunettaAV_WIP.sch]
2021-06-23 Add compartor section
    [LunettaAV_WIP.sch]
2021-06-23 Teensy patternSelector + schematic fixes
    [LunettaAV_WIP.sch]
2021-06-23 Change startup and reset functions
    [LunettaAV.ino]
2021-06-24 Add 4094, 4017, 4040 and 4051 sections
    [LunettaAV_WIP.sch]
2021-06-24 fix 4051 issues
    [LunettaAV_WIP.sch]
2021-06-25 changes to schematics. brd file ignore for now.
    [LunettaAV_WIP.brd, LunettaAV_WIP.sch]
2021-06-25 scehmatics fixes
    [LunettaAV_WIP.brd, LunettaAV_WIP.sch]
2021-07-06 schematic updates
    [LunettaAV_WIP.brd, LunettaAV_WIP.sch]
2021-07-09 more visuals and functions updated
    [LunettaAV_WIP.brd, LunettaAV_WIP.sch]
2023-03-27 fix 4017 schematics
    [LunettaAV_WIP.brd, LunettaAV_WIP.sch]
2023-03-27 change melody out config and buffer the out for later stage
    [LunettaAV_WIP.brd, LunettaAV_WIP.sch]
2023-03-28 PT2399 init + screen changed
    [LunettaAV_WIP.brd, LunettaAV_WIP.sch]
2023-03-28 PT Delay and other fixes
    [LunettaAV_WIP.brd, LunettaAV_WIP.sch]
2023-03-28 fix Arduino code errors
    [LunettaAV.ino]
2023-03-28 update schematics to match new code
    [LunettaAV_WIP.brd, LunettaAV_WIP.sch]
2023-03-29 finish schematics?
    [LunettaAV_WIP.brd, LunettaAV_WIP.sch]
2023-03-29 add more caps no cap
    [LunettaAV_WIP.sch]
2023-03-29 code cleanups and parity among eagle and teensy naming schema
    [LunettaAV_WIP.brd, LunettaAV_WIP.sch]
2023-03-29 brd init
    [LunettaAV_WIP.brd, LunettaAV_WIP.sch]
2023-03-29 PCB Design
    [LunettaAV_WIP.brd, LunettaAV_WIP.sch]
2023-03-29 redo routing
    [LunettaAV_WIP.brd, LunettaAV_WIP.sch]
2023-03-29 fix minor schematic issues for a cleaner bom
    [LunettaAV_WIP.brd, LunettaAV_WIP.sch]
2023-03-29 minor cleanups
    [LunettaAV_WIP.brd]
2023-03-30 redesign board for mounting holes
    [LunettaAV_WIP.brd, LunettaAV_WIP.sch]
2023-03-30 more changes and gerber for ordering
    [LunettaAV_WIP.brd, LunettaAV_WIP.sch]
2023-04-12 fixes modifications and beautification for rev 2
    [LunettaAV_WIP.brd, LunettaAV_WIP.sch]
2023-04-12 rev 2 routing
    [LunettaAV_WIP.brd]
2023-07-31 v2 rc
    [LunettaAV_WIP.brd]
2024-02-27 add two patterns
    [LunettaAV_WIP.sch]
2024-09-26 add gnd to 4040 res
    [LunettaAV_WIP.brd, LunettaAV_WIP.sch]
2024-09-26 rev 2 updates
    [LunettaAV_WIP.brd]
2024-09-26 add BOM
    [N8IR_BOM_20240926.csv]
2024-09-27 Add pdf schematics

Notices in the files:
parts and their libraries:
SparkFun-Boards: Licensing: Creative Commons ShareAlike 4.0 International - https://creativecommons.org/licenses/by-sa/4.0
